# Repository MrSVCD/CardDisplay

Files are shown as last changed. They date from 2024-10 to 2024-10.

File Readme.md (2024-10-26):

# OLED display magnifier

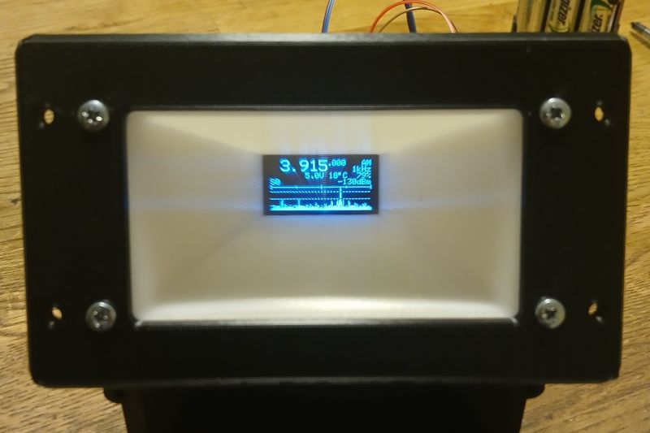
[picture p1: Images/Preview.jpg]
Display magnifier assembled.
 

These 3D models is made to make 0.96" OLED display more readable by using a credit card sized Fresnel lens.

The model are designed in OpenSCAD.

In the file `CardDisplay-Back.scad` the variable **h** is the length from the front of the lens to the front of the OLED display in mm.

## Print and Build instructions

Read [Build.md](Build.md)

## Rendering Instructions

Rending needs the following software:

* OpenSCAD
* GNU Parallel
* advzip from advancecomp **or** zip from Info-Zip

To render run render.sh
```
$> ./render.sh
```
This will create CardDisplay.zip with all the STLs inside.

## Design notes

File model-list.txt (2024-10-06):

openscad -D h=10 -o CardDisplay-Back10.stl CardDisplay-Back.scad
openscad -D h=20 -o CardDisplay-Back20.stl CardDisplay-Back.scad
openscad -D h=30 -o CardDisplay-Back30.stl CardDisplay-Back.scad
openscad -D h=40 -o CardDisplay-Back40.stl CardDisplay-Back.scad
openscad -D h=50 -o CardDisplay-Back50.stl CardDisplay-Back.scad
openscad -D h=60 -o CardDisplay-Back60.stl CardDisplay-Back.scad
openscad -D h=70 -o CardDisplay-Back70.stl CardDisplay-Back.scad
openscad -D h=80 -o CardDisplay-Back80.stl CardDisplay-Back.scad
openscad -D h=90 -o CardDisplay-Back90.stl CardDisplay-Back.scad
openscad -o CardDisplay-Front.stl CardDisplay-Front.scad
openscad -o DisplayClips.stl DisplayClips.scad

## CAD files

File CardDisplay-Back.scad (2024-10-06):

$fn=90;
h=80;

difference(){
    union(){
        minkowski(){
            union(){
                hull(){
                    translate([3,3]) hull(){
                        translate([   2,   2,0])cylinder(h=1,r=2);
                        translate([   2,43-2,0])cylinder(h=1,r=2);
                        translate([80-2,   2,0])cylinder(h=1,r=2);
                        translate([80-2,43-2,0])cylinder(h=1,r=2);
                        translate([80/2,(43/2)]) translate([-25/2,-13/2,h])cube([25,13,1]);
                    }
                }
                
                hull(){
                    translate([86/2,(43/2)+3]) translate([-29/2,-10.5-6,h]) cube([29,28,4]);
                    translate([86/2,(43/2)+3]) cube([1,1,1],center=true);
                }
            }
            cylinder(h=1,r=2);
        }
        minkowski(){
            cube([86,55,4]);
            cylinder(h=1,r=3);
        }
 
        translate([86/2,55/2]){
            translate([-31/2,5]) cylinder(h=h+5,r=3);
            translate([ 31/2,5]) cylinder(h=h+5,r=3);
            translate([-31/2,-15]) cylinder(h=h+5,r=3);
            translate([ 31/2,-15]) cylinder(h=h+5,r=3);
        }

        translate([  -2,55-10]) cylinder(h=10,d=7);
        translate([  -2,    5]) cylinder(h=10,d=7);
        translate([86+2,55-10]) cylinder(h=10,d=7);
        translate([86+2,    5]) cylinder(h=10,d=7);
    }

    cube([86,55,1.5]);

    translate([3,3]) hull(){
        translate([   2,   2,-8])cylinder(h=10,r=2);
        translate([   2,43-2,-8])cylinder(h=10,r=2);
        translate([80-2,   2,-8])cylinder(h=10,r=2);
        translate([80-2,43-2,-8])cylinder(h=10,r=2);
        translate([80/2,(43/2)]) translate([-25/2,-13/2,h])cube([25,13,1]);
    }

    translate([86/2,(43/2)+3]) translate([-29/2,-10.5-6,h]) {
        translate([0,0,3]) cube([29,28,2]);
        translate([1,8/2,1]) cube([27,20,4]);
        translate([(29-12)/2,0,1]) cube([12,28,6]);
    }

    translate([86/2,(43/2)+3]) translate([-25/2,-13/2,h])cube([25,13,1]);

    translate([86/2,55/2]){
        translate([-32/2,  5,h-2]) cylinder(h=10,d=2.8);
        translate([ 32/2,  5,h-2]) cylinder(h=10,d=2.8);
        translate([-32/2,-15,h-2]) cylinder(h=10,d=2.8);
        translate([ 32/2,-15,h-2]) cylinder(h=10,d=2.8);
    }

    translate([  -2,55-10]) cylinder(h=10,d=2.8);
    translate([  -2,    5]) cylinder(h=10,d=2.8);
    translate([86+2,55-10]) cylinder(h=10,d=2.8);
    translate([86+2,    5]) cylinder(h=10,d=2.8);

    translate([-25,-25,-1])cube([200,200,2.5]);
}

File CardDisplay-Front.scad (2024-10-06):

$fn=90;

difference(){
    minkowski(){
        translate([-15,-10,1]) cube([86+30,70,1]);
        cylinder(h=4,r1=2,r2=4);
    }

    translate([0,0,4.5]) cube([86,55,2]);

    translate([3,3]) hull(){
        translate([   2,   2])cylinder(h=10,r=2);
        translate([   2,43-2])cylinder(h=10,r=2);
        translate([80-2,   2])cylinder(h=10,r=2);
        translate([80-2,43-2])cylinder(h=10,r=2);
    }

    translate([  -2,55-10]) cylinder(h=10,d=3.2);
    translate([  -2,    5]) cylinder(h=10,d=3.2);
    translate([86+2,55-10]) cylinder(h=10,d=3.2);
    translate([86+2,    5]) cylinder(h=10,d=3.2);

    translate([  -12,55-10]) cylinder(h=10,d=3.2);
    translate([  -12,    5]) cylinder(h=10,d=3.2);
    translate([86+12,55-10]) cylinder(h=10,d=3.2);
    translate([86+12,    5]) cylinder(h=10,d=3.2);
}

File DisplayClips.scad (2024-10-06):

$fn=90;
difference(){
    union(){
        hull(){
            cylinder(h=3,d=7);
            translate([20,0]) cylinder(h=3,d=7);
        }
        translate([0,1.6])cube([2,1.9,3.5]);
        translate([18,1.6])cube([2,1.9,3.5]);
    }
    cylinder(h=10,d=3.2);
    translate([20,0]) cylinder(h=10,d=3.2);
}

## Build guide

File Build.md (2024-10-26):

# Print and Build instructions

Preview of the display magnifier assembled. 
(The lens flare is not visible in person)

## Printing

When you print this you need print 1 of the `CardDisplay-Back#0.stl.`, 1x `CardDisplay-Front.stl` and 2x `DisplayClips.stl`. These files are in the CardDisplay.zip file.

The number on the end of `CardDisplay-Back#0.stl` is the length from the front of the lens to the front of the OLED display in mm. To find out what length you need take your lens and hold it up to the OLED display and measure the distance that is comfortable for you.

You probably need to unzip the files before using them with your slicer.

**Note:** I have noticed that the `CardDisplay-Back#0.stl` part in my black filament was too reflective for my taste so chose your filament wisely, I used a natural PLA and it is matte enough.

## Building

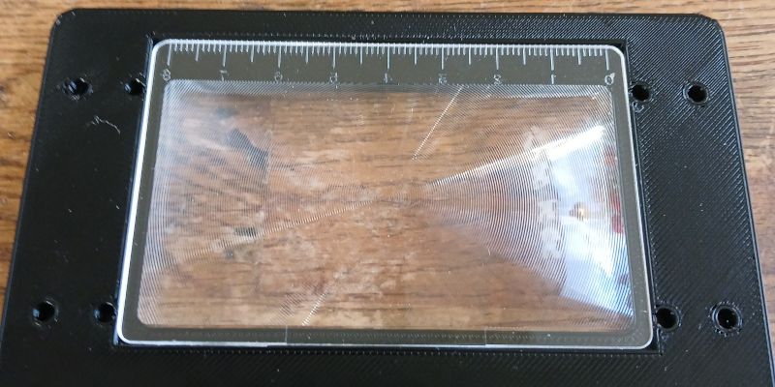
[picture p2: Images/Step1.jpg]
Front piece with lens placed in its grove.
 

Take the Front part and place your lens in its grove.

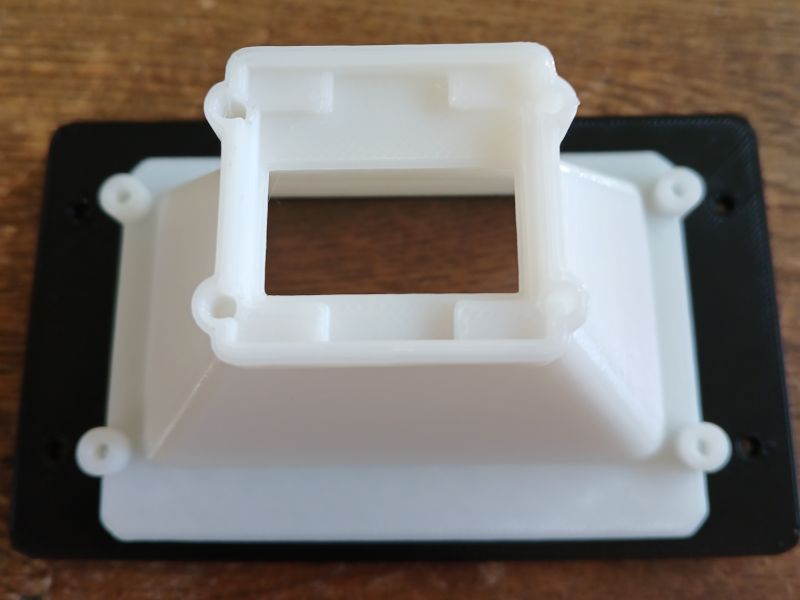
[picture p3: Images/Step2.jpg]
Front piece with Back piece placed on top of it.
 

Take the Back piece and place it on the Front so it covers the whole lens and turn it over.

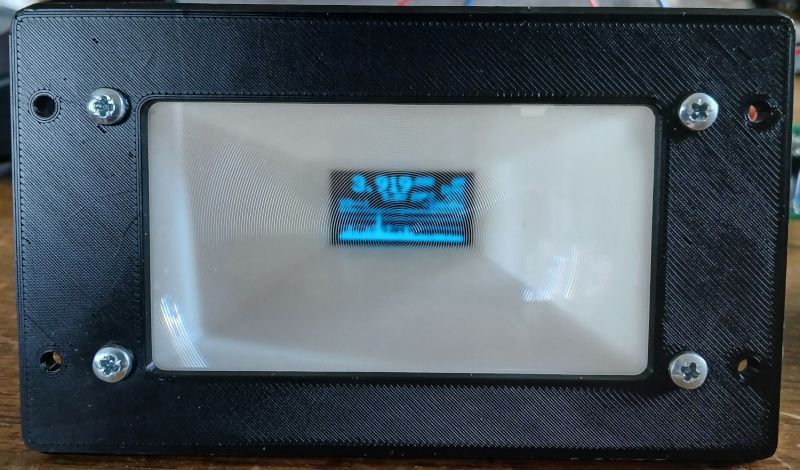
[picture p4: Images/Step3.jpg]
Front piece with lens and screws holding the Back piece in pace.
 

Take 4 M3x10 screws and fasten the Back piece to the Front piece using the inner holes as shown. Turn it over again.

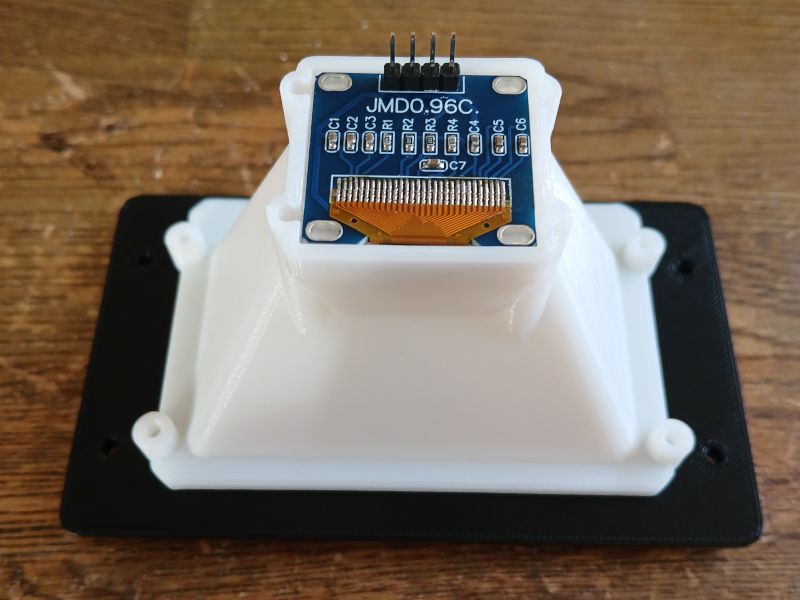
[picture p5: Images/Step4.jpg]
Magnifier with backside up and a OLED placed in its slot.
 

Place the OLED display in the slot on the Back piece of the magnifier.

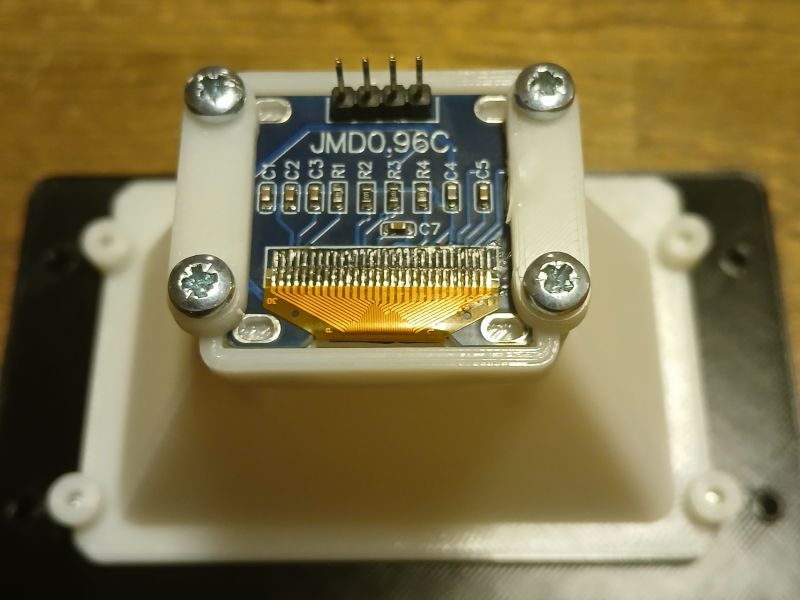
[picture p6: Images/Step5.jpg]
Magnifier with backside up and a OLED held in place with display clips and screws.
 

Use the DisplayClips and 4 M3x10 screws and lock the OLED display in place.

Preview of the display magnifier assembled. 

A complete display magnifier with [PicoRX](https://github.com/dawsonjon/PicoRX)  running on the display.

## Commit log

2024-10-06 Initial upload of files.
    [CardDisplay-Back.scad, CardDisplay-Front.scad, DisplayClips.scad]
2024-10-06 Added Print instructions
2024-10-06 Added print and build instructions
